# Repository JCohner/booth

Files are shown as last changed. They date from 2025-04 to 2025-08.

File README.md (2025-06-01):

# Booth Controller

Using ~1000 NeoPixels with FastLED library we are controlling a custom built DJ booths lighting.
The NeoPixels are organzied into rectangles on a DJ of which the light difuses around the rectnagle. 
This is using the SAMD21 broken out via the arduino nano 33 iot board. 

## Code Organization
* `booth_controller` contains the arduino sketch
  * `booth_controller.ino`
    * instantiates the DMX receiver very inspired by [this library](https://github.com/claudeheintz/LXSAMD21DMX/tree/master)
    * instantiates the custom LightingArrayController object
    * overrides the standard Serial1 handler SERCOM5 to specifically parse DMX inputs from the RS485 transciever 
    * sets up the dmx object and light controller
    * grabs dmx data and passes it to the light controller to map to rectangles
  * lighting_array_controller
    * **note** in both .h and .cpp file there is auto generated code parsed from the csv that keeps the rectangles aligned with reality. See rect_gen.py for more. 
    * **important** holds array of CRGB leds from FastLED 
    * handles business logic of holding array of rectangles and passing dmx channels to their relevant rectangle
    * critically calls FastLED.show()
  * rectangle
    * mechanisim to map global array of LEDs to given logical rectangle
    * has rectangle specific dmx_update mechanism which takes mapped dmx channels and translates to LED CRGB values
  * dmx
    * does dmx things, neat protocol. thanks to claudeheintz
* requirements.txt, rect_gen.py, rects.csv
  * all convinience things for autogenerating cpp code to map the rectangles
* Makefile
  * compile - compiles 'primary' and 'secondary' to cover both arduinos
  * deploy_[primary, secondary] - deploys relevant binary to MCU

## TODO attach pictures it looks sweet take my word for it for now.

### Notes:
Added: `void SERCOM5_Handler() __attribute__((weak));` to the relevant variants.cpp file such that I could overwrite the SERCOM5 handler being used for Serial1 to parse out the DMX messages

It seems my one nano was just not powerful enough to write to all 1000+ LEDs, I put another on the DMX bus and mapped it to the channels my first couldn't meet.

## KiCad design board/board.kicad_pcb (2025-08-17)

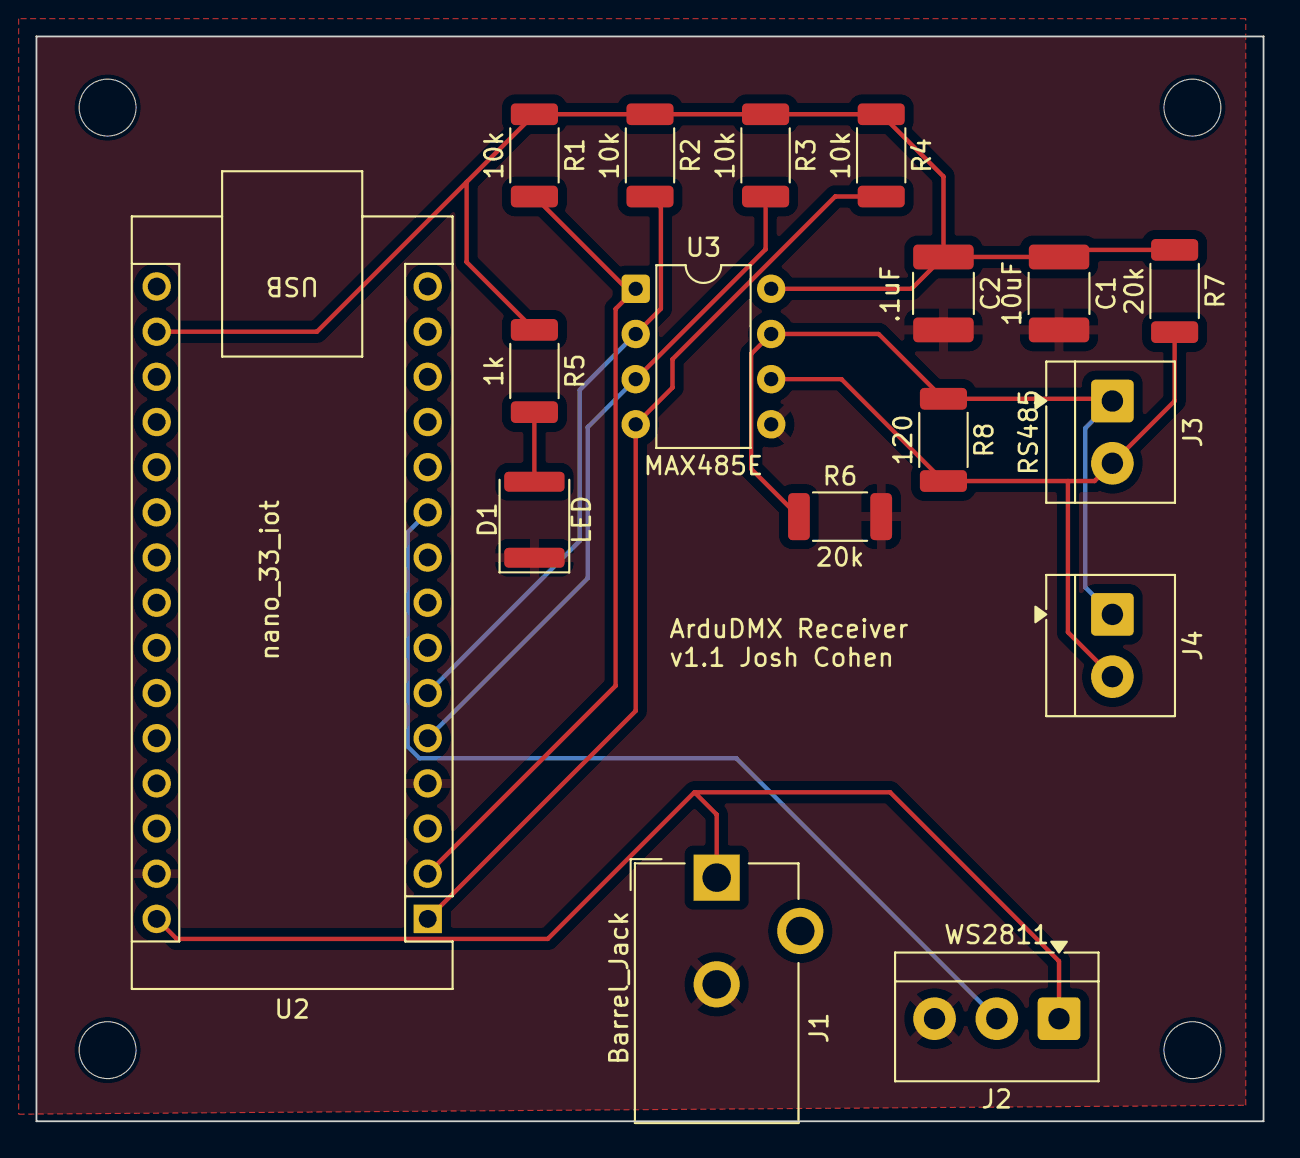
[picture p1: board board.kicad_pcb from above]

Board: 2 copper layers, 69.0 x 61.0 mm, 21 parts (0 on the bottom side), 11 nets.

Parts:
C1: 10uF; C_1812_4532Metric
C2: .1uF; C_1812_4532Metric
D1: LED; LED_1812_4532Metric
H1, H2, H3, H4: MountingHole_Pad; MountingHole_3.2mm_M3
J1: Barrel_Jack; BarrelJack_CUI_PJ-102AH_Horizontal
J2: WS2811; TerminalBlock_4Ucon_1x03_P3.50mm_Horizontal
J3, J4: RS485; TerminalBlock_4Ucon_1x02_P3.50mm_Horizontal
R1, R2, R3, R4: 10k; R_2010_5025Metric
R5: 1k; R_2010_5025Metric
R6, R7: 20k; R_2010_5025Metric
R8: 120; R_2010_5025Metric
U2: nano_33_iot; Arduino_Nano
U3: MAX485E; DIP-8_W7.62mm

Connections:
+3.3V: C1.1, C2.1, R1.1, R2.1, R3.1, R4.1, R5.1, R7.1, U2.17 (3v3), U3.8 (VCC)
+5V: J1.1, J2.1, U2.30 (VIn)
/DE: R3.2, U2.5 (DE), U3.3 (DE)
/DI: R4.2, U2.1 (DI|tx), U3.4 (DI)
/RE: R2.2, U2.6 (RE), U3.2 (~RE)
/RO: R1.2, U2.2 (RO|rx), U3.1 (RO)
/cnt_sign: J2.2, U2.10 (cnt_sig)
GND: C1.2, C2.2, D1.1 (K), J1.2, J2.3, R6.2, U2.4 (GND), U2.29 (GND), U3.5 (GND)
unnamed: D1.2 (A), R5.2
unnamed: J3.1, J4.1, R6.1, R8.1, U3.7 (B)
unnamed: J3.2, J4.2, R7.2, R8.2, U3.6 (A)

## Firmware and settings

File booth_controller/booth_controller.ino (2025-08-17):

#include "wiring_private.h"
#include "lighting_array_controller.h"

#include "dmx.h"
DMX dmx;

LightingArrayController light_cont;

// DMX Input
void SERCOM5_Handler()
{
  if ( SERCOM5->USART.INTFLAG.bit.ERROR ) {
    SERCOM5->USART.INTFLAG.bit.ERROR = 1;   //acknowledge error, clear interrupt
    
    if (SERCOM5->USART.STATUS.bit.FERR){ // silly but universal way they seem to detect new DMX packet
      dmx.break_received();
      return;
    }
  
  }
  if ( SERCOM5->USART.INTFLAG.bit.RXC ) {
    uint8_t incoming_byte = SERCOM5->USART.DATA.reg;       // read buffer to clear interrupt flag
    dmx.byte_received(incoming_byte);
  } // RXC
}

void setup() {
  Serial.begin(9600);
  //while(!Serial){;}
  
  // DMX Receiving 
  Serial1.begin(250000);
  dmx.setup();

  light_cont.setup();

  pinMode(3, OUTPUT);
  pinMode(2, OUTPUT);
  pinMode(4, OUTPUT);
  digitalWrite(3, LOW);
  digitalWrite(2, LOW);
  digitalWrite(4, LOW);
  
  delay(100);
}
    
void loop() {
  // map dmx to light controller in 3 channel mode:
  static int egg = 0; // sometimes its nice to see an incrementing number
  uint8_t* data;
  uint16_t num_slots = dmx.get_dmx_packet(&data);

  //Serial.println(egg++);
  light_cont.dmx_update(data, num_slots);
}

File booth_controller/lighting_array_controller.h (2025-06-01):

#ifndef __CONTROLLER_H__
#define __CONTROLLER_H__

#include <FastLED.h>
#include "rectangle.h"

// Setup Custom Parameters
#define LED_COUNT 410
#define NUM_RECTANGLES 20
#define DMX_OFFSET 88
// End Custom Parameters

#define CONTROL_PIN 7
#define MASTER_DMX_DMX_CHANNEL 1 // Don't forget DMX is effectivley 1 indexed. We are putting master dimmer on Chan 1

class LightingArrayController {
public:
  LightingArrayController() {};
  void setup();
  void dmx_update(uint8_t* dmx_frame, uint16_t num_channels);
private:
  CRGB leds_[LED_COUNT];
  uint8_t master_dimmer_;
  Rectangle rects_[NUM_RECTANGLES];
};

#endif /* __CONTROLLER_H__ */

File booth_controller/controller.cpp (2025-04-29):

#include <Arduino.h>
#include <math.h>
#include <stdint.h>
#include <stdlib.h>
#include <avr/dtostrf.h>
#include <fast_samd21_tc5.h>
#include "controller.h"


void Controller::tick(){
  static uint8_t rval, bval, gval;
  static uint32_t tick = 0;
  tick++;
  for (int i =0; i < NUM_RECTANGLES; i++){
    Rectangle rect = rects_[i]; 
    rect.update(tick);
  }
  FastLED.show();
}

void Controller::setup(){
  FastLED.addLeds<NEOPIXEL, CONTROL_PIN>(leds_, LED_COUNT).setCorrection(TypicalLEDStrip);;  // GRB ordering is assumed
  FastLED.setBrightness( 255 );

  // setup rectangles
  rects_[0] = Rectangle(0, 5);
  rects_[1] = Rectangle(5, 10);
  rects_[2] = Rectangle(15, 20);
  rects_[3] = Rectangle(35, 10);
  rects_[4] = Rectangle(45, 15);

  int gen_off = 0;
  Serial.print("leds is at: ");
  Serial.println((int)leds_);

  for (int i = 0; i < NUM_RECTANGLES; i++){
    Serial.print("Assigning ");
    Serial.println((int)(leds_ + gen_off));
    rects_[i].leds_ = leds_ + gen_off;
    gen_off += rects_[i].count();
  }
}

void Controller::enqueue_message(char * buff, int size){
  if (size <= 0) return;
  char egg[100];
  int val;
  int rect;
  float valf;
  int ind = 3;
  Serial.print("swithcing on: ");
  Serial.println(buff[0]);
  switch(buff[0]){
    case 'q':
      fast_samd21_tc5_configure(30000); // starts the timer/trigger with 30ms
      //memset(color_map, 0, sizeof(color_map));
      break;
    case 'a':
    case 'o':
    case 'f':
      valf = atof(buff+3);
      Serial.println(buff[1]);
      rect = atoi(&buff[1]);
      switch(buff[2]){
        case 'r':
          ind = 0;
          break;
        case 'g':
          ind = 1;
          break;
        case 'b':
          ind = 2;
          break; 
      }
      if (ind != 3){
        char fs[10];
        // dtostrf(valf, 4, 2, fs);
        sprintf(egg, "For rect %d Writing value %c, %c to ",rect, buff[0], buff[2]);
        Serial.print(egg);
        Serial.println(valf);
        if (buff[0] == 'f'){
          rects_[rect].set_frequency(ind, valf);
        } else if (buff[0] == 'a'){
          rects_[rect].set_amplitude(ind, valf);
        } else if (buff[0] == 'o'){
          rects_[rect].set_offset(ind, valf);
        }
      }
      break;
  }
}

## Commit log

2025-04-21 switched to fastled
2025-04-29 switch to nano 33 iot
2025-05-23 got a rectangle to c code parser with brandongit add -u
    [rects.csv]
2025-05-28 big change
    [rects.csv]
2025-05-29 better py
    [rects.csv]
2025-05-31 figured it out
    [rects.csv]
2025-05-31 feat: bringing it back to one piece of source code thats compiled twice one for each dmx device with given paramters loaded in automatically
2025-08-17 board v1.1
    [board.kicad_pcb, board.kicad_sch]
